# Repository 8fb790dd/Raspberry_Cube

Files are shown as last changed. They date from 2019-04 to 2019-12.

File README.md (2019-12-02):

# Raspberry_Cube
3D printable Case for Raspberry Pi 3B+ **Cluster** 

- stackable frame size 60x60x90 (without fan)
- consists of 4 printable parts (base-, mid- and top-plate, 30mm fan adapter)
- for two Raspberry PI's 3B+ with standard heatsinks on cpu, lan & memory
- for 60mm Fan or alternative 30mm Fan with additional adapter

### adapter
- [x] adapter for one 30mm fan for 1 Cube (2 Pi's)
- [ ] adapter for one 60mm fan for 2 stacked Cubes (4 Pi's)
- [ ] adapter for one 30mm fan for 2 stacked Cubes (4 Pi's)

### [ ] test effectiveness of design
  - [x] test one Cube with 30mm fan, running 2 Pi 3B+; see [test description](test1.md) and results.
  - [ ] test one Cube with 60mm fan, running 2 Pi 3B+
  - [ ] test two stacked Cubes with 60mm fan, running 4 Pi's 3B+

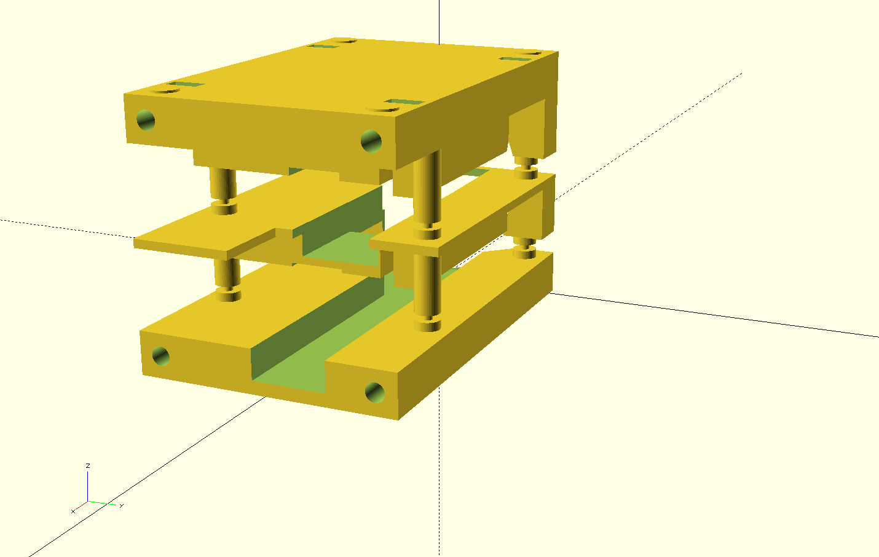
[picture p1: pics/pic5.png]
cube


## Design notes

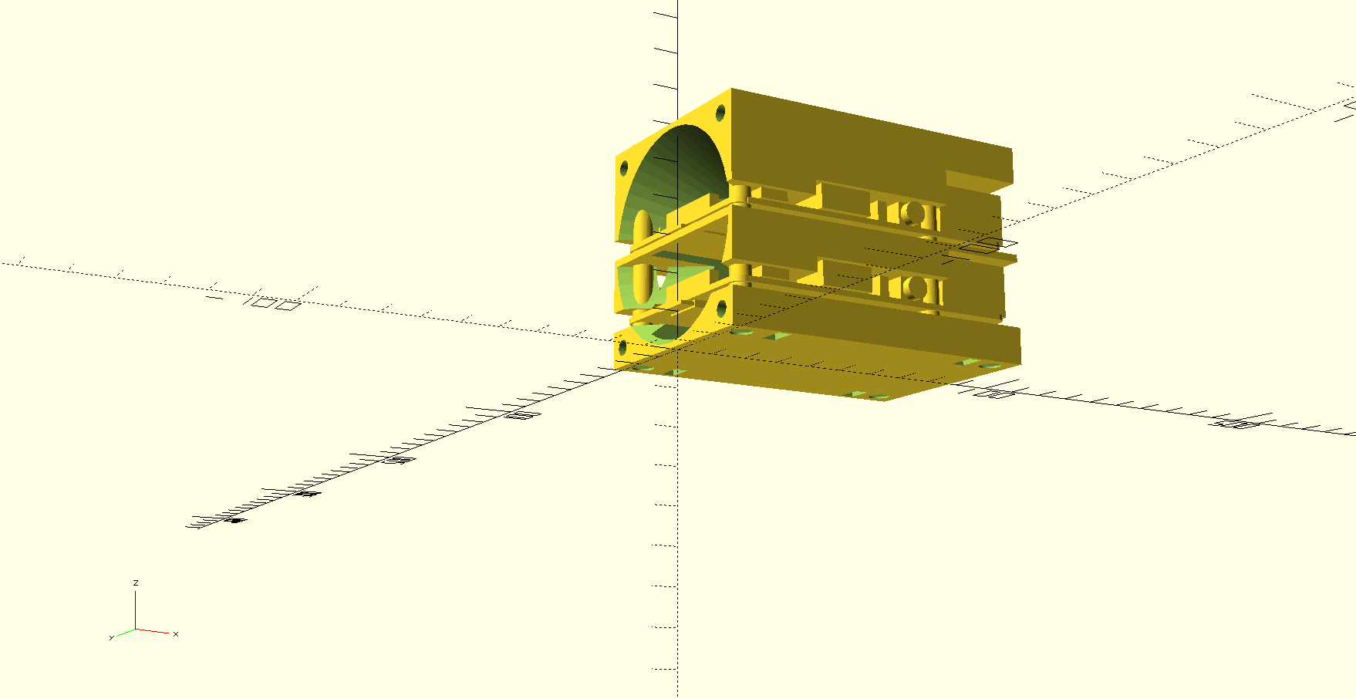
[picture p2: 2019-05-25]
pics/pic3.png

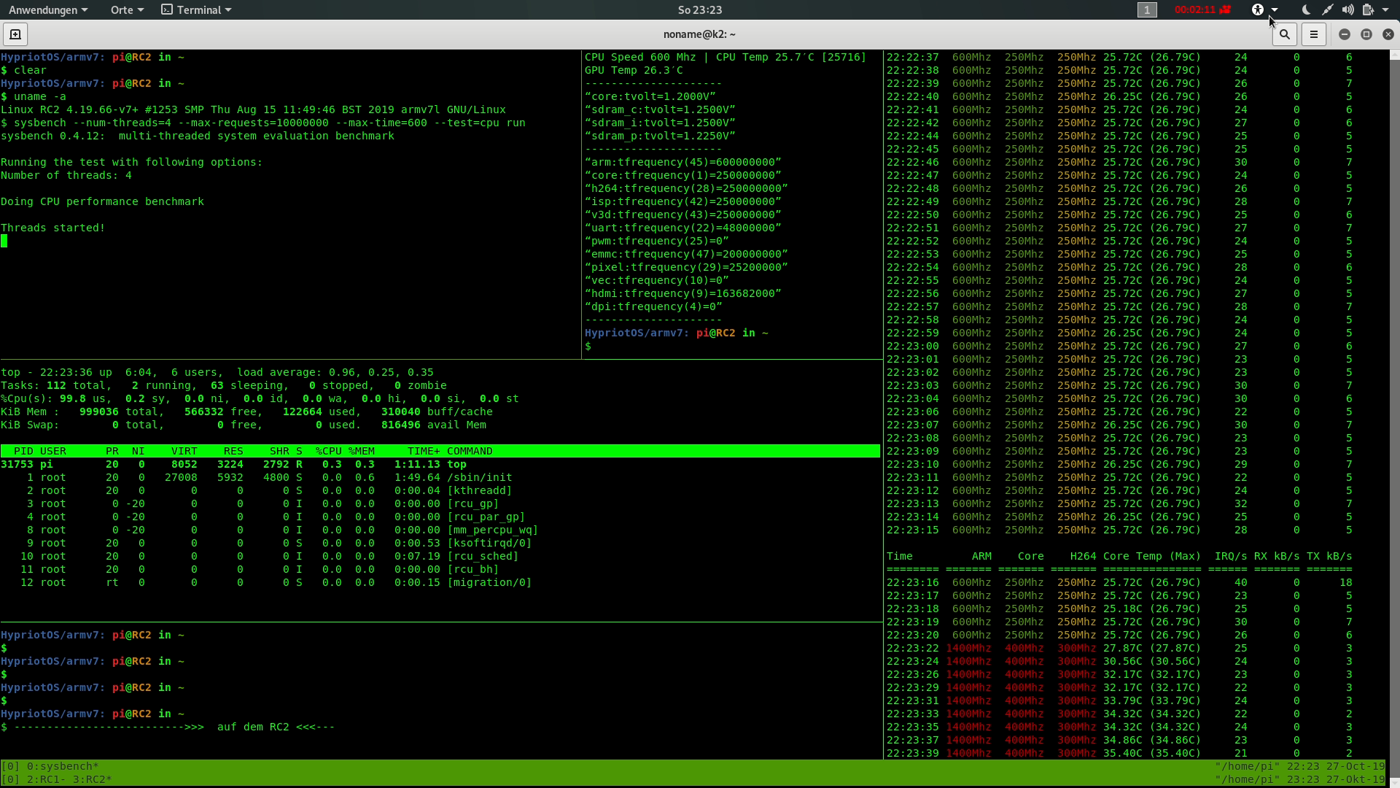
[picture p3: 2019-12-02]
pics/RC2_Start_Load_Screenshot from Screencast_27.10.2019_23:21:28.mp4.png

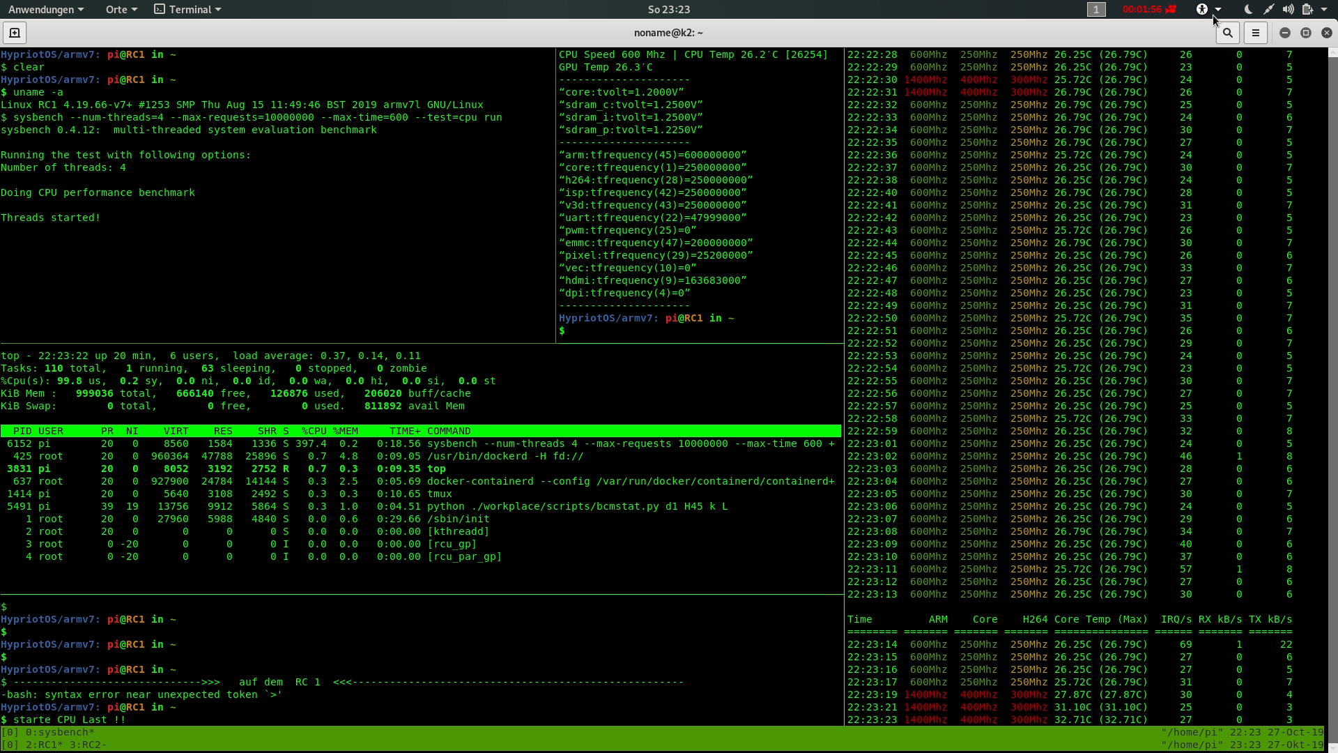
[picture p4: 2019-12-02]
pics/RC1_Start_Load_Screenshot from Screencast_27.10.2019_23:21:28.mp4.png

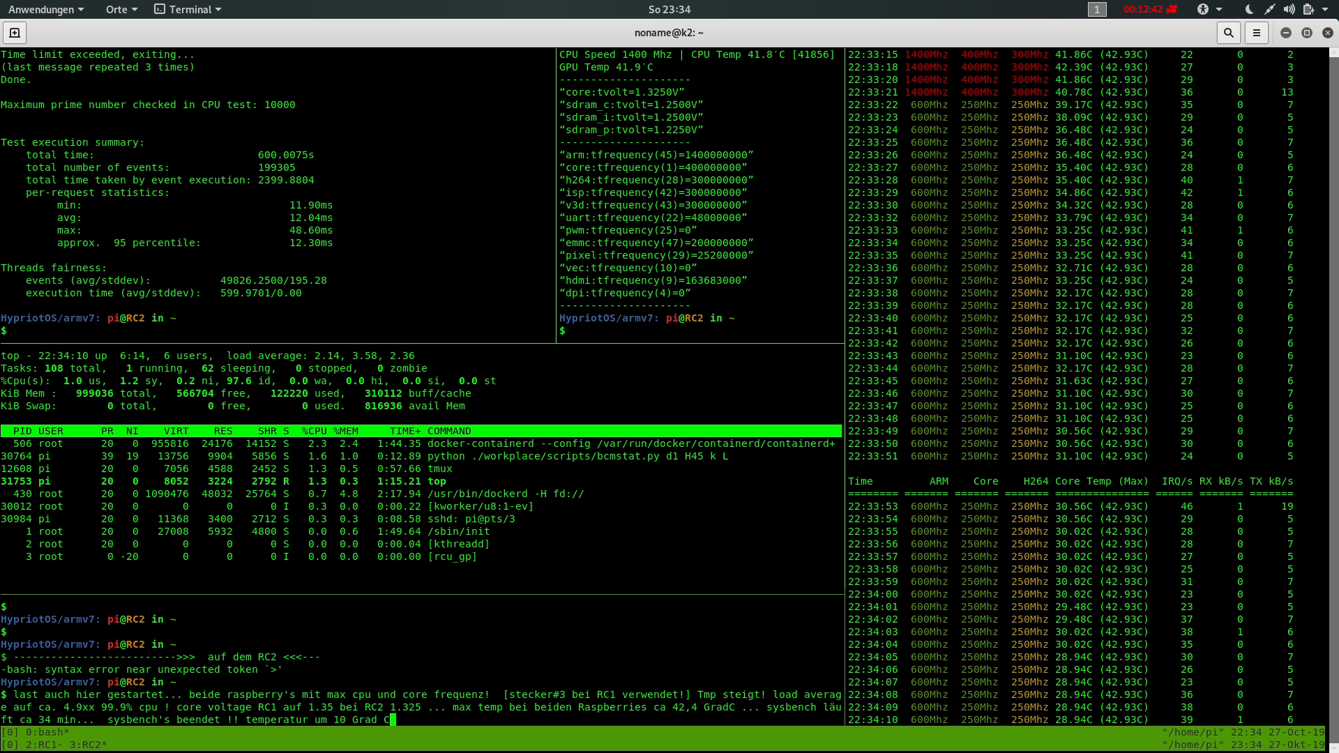
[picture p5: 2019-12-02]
pics/RC2_CoolDown_Screenshot from Screencast_27.10.2019_23:21:28.mp4.png

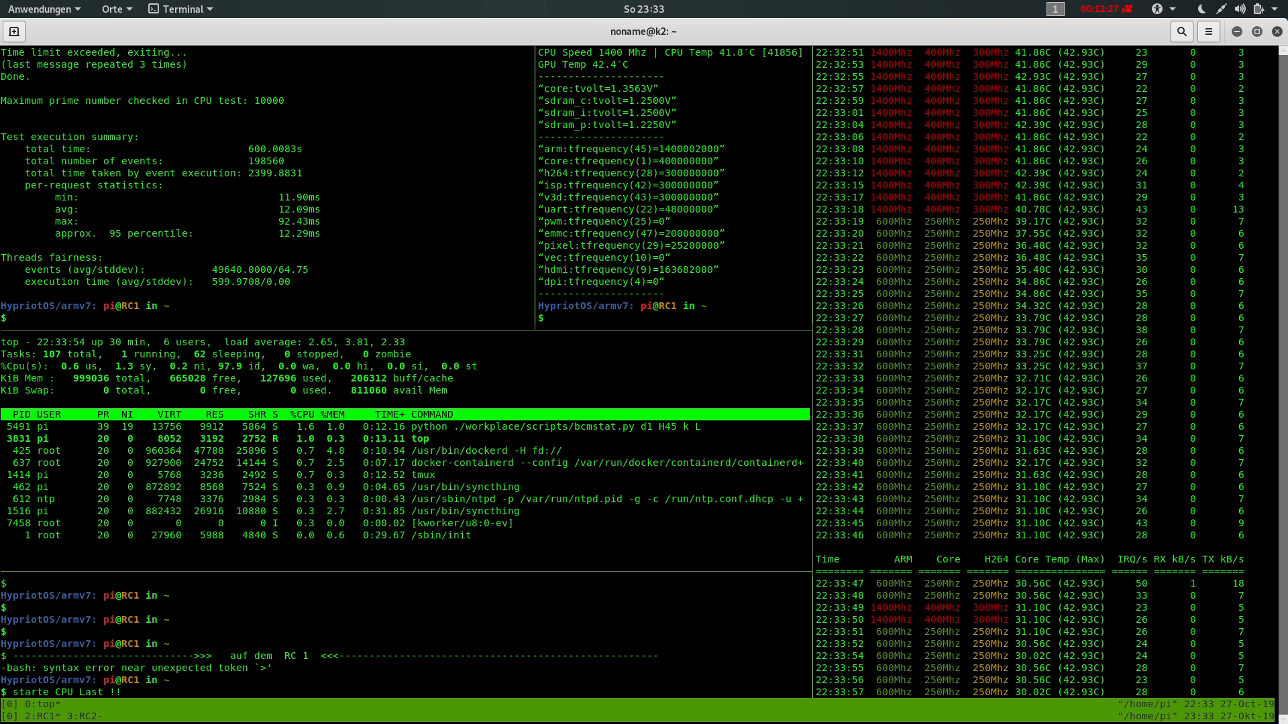
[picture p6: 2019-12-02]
pics/RC1_CoolDown_Screenshot from Screencast_27.10.2019_23:21:28.mp4.png

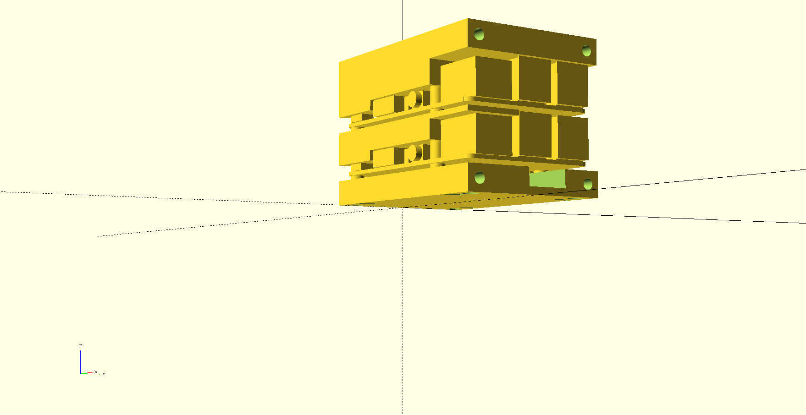
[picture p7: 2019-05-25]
pics/pic4.png

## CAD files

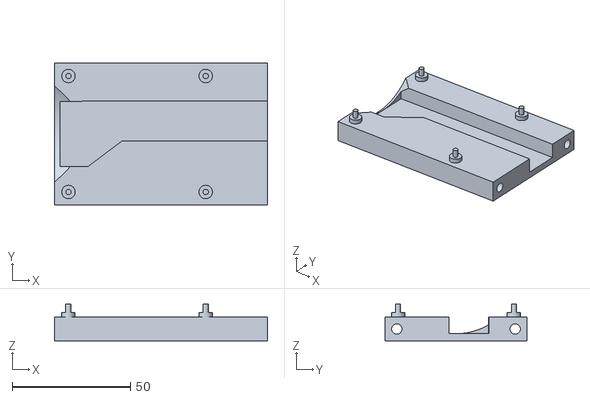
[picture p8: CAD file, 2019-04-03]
190401_Low_Frame.stl
90.0 x 60.0 x 15.5

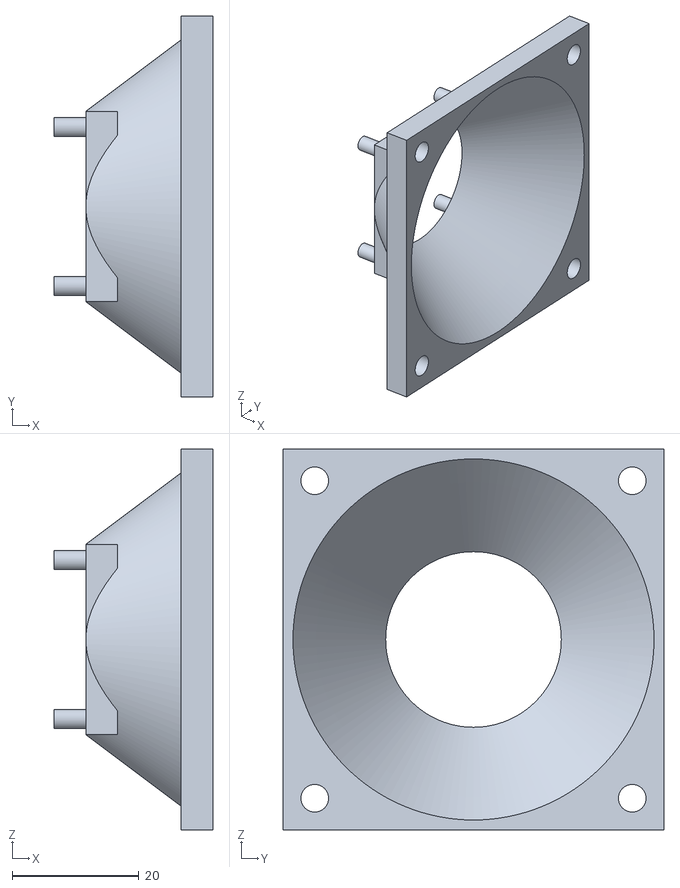
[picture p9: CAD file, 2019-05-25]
stl/190411_RB_Fan_Frame.stl
25.0 x 60.0 x 60.0

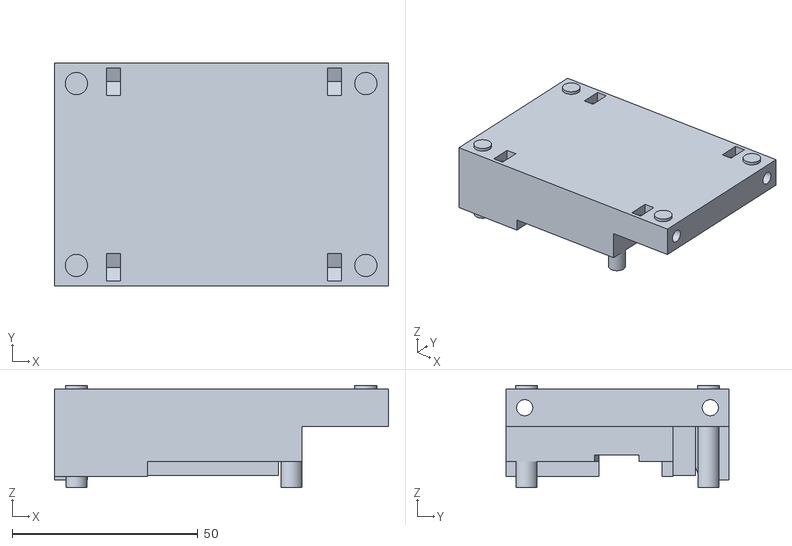
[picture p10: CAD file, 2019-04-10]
stl/190410_RB_Top_Frame.stl
90.0 x 60.0 x 27.5

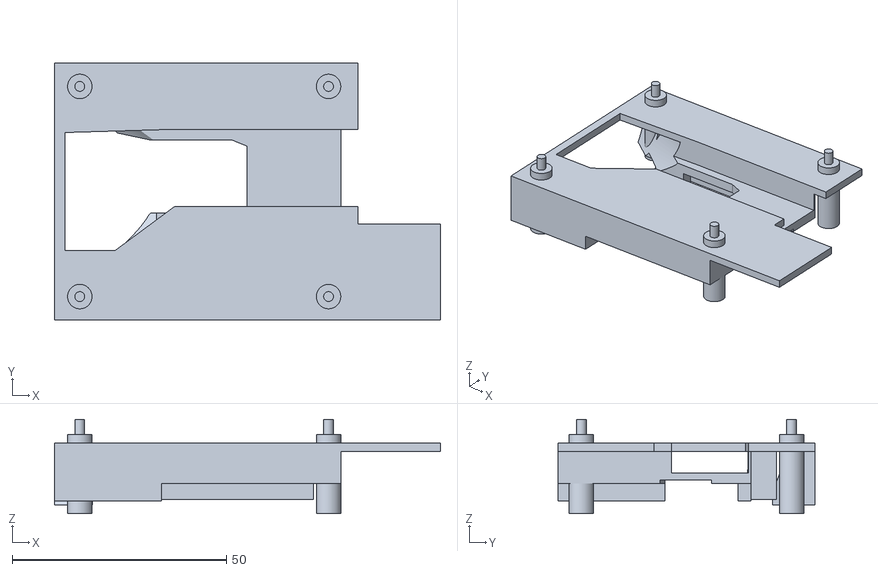
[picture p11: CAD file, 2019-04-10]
stl/190410_RB_Mid_Frame.stl
90.0 x 60.0 x 22.0

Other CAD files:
stl/190410_RB_Low_Frame.stl

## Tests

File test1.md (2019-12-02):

# test cooling of "Raspberry_Cube" case
## 27.10.2019 23:21
#### reference: f8ff9a73f449049f0244390ff263996b0694c69f  Screencast_27.10.2019_23:21:28.mp4
3D printable Case for Raspberry Pi 3B+ **Cluster** 

1. test **scenario**
  - 2 raspberry Pi 3B+ running in cube, headless named **RC1** & **RC2**
  - powered by 4 port 16 Watt USB power supply device (5.1V with max sum current 3.1A) 
  - 30mm fan running with 5V
  - environment temperature ca. 20 GradC
  - remote login to both Pi's via ssh and tmux
  - 2 nearly identical screens with panes for 
      online temp logging, voltages, top, start of load, ...

2. test procedureadded pics of 3d printed cases with 2 stacked Raspberries 3B+
  - start of sysbench on each pi's nearly simultan
  - run time of sysbench for 10 minutes (600 secs)
  - switching between screens to control voltage, temp and freq.

3. main results
  - after idle running for some minutes, the temperature started at ca. **26.8 Grad C** on each Pi
  - start full load with sysbench for 10 minutes
  - **max temperature** reached stayed below **43 Grad C** on each Pi
  - **no throttling** of cpu/gpu freq seen...

4. rough progress of RC2, (RC1 quiete similar)
  - 30 Grad C	4 sec
  - 32 Grad C	6 sec
  - 34 Grad C	13 sec
  - 36 Grad C	26 sec
  - 38 Grad C	38 sec
  - 40 Grad C	78 sec  1:18 min
  - 41 Grad C	146 sec	2:26 min
  - 42 Grad C	304 sec	4:24 min

## used screen logging
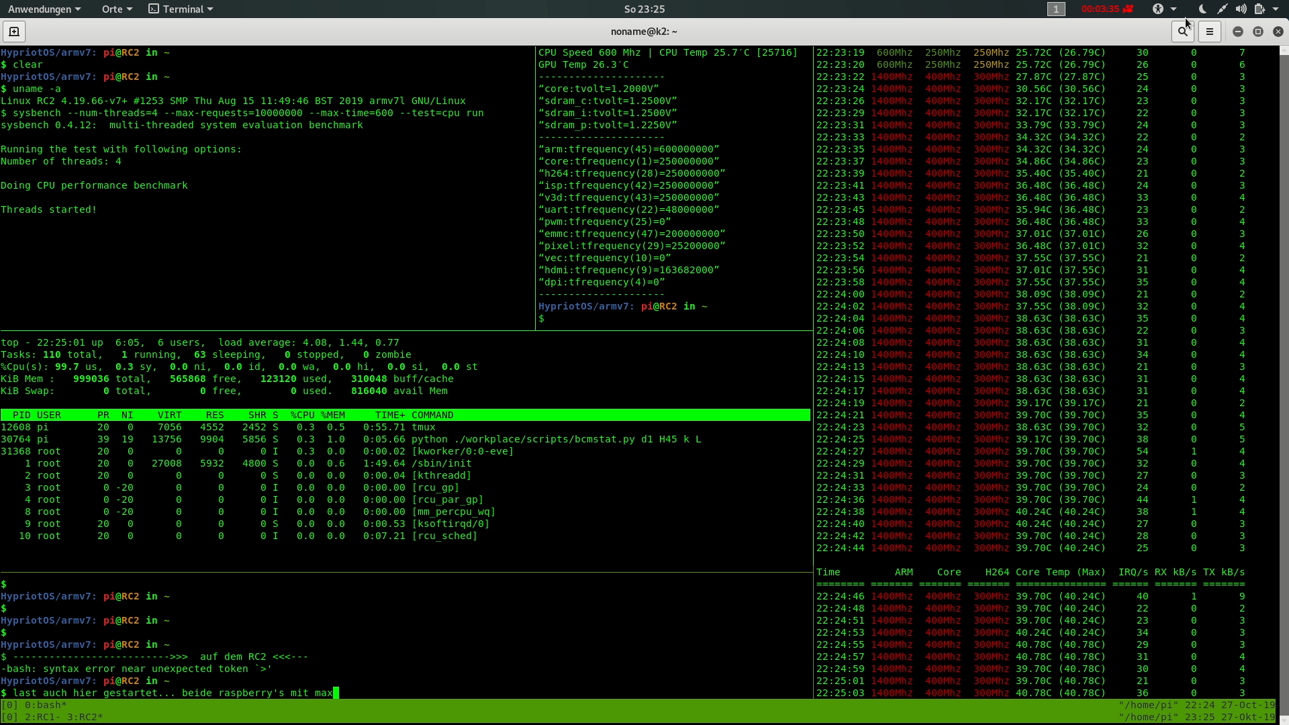
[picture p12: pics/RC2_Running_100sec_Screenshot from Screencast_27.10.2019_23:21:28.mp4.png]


## used "Cube" case
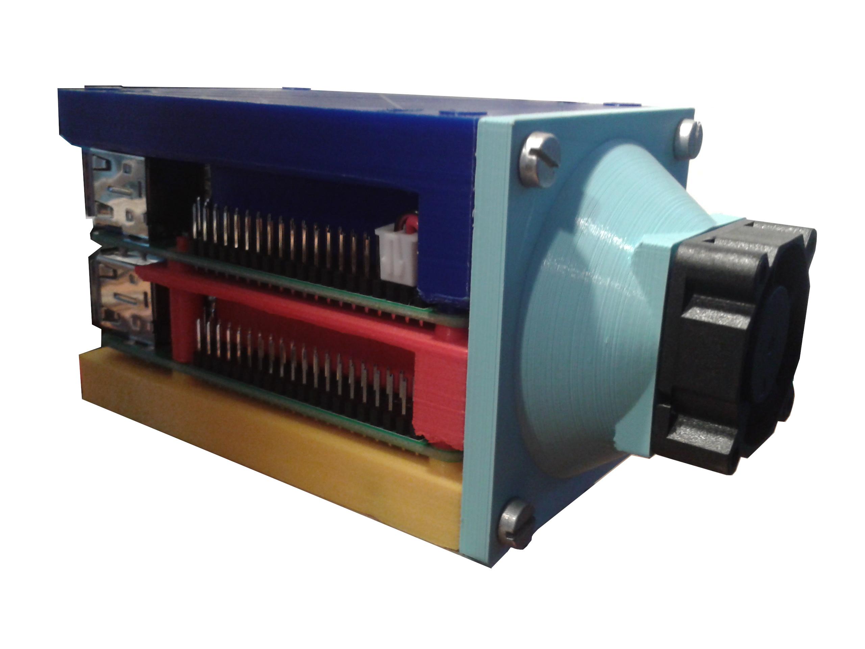
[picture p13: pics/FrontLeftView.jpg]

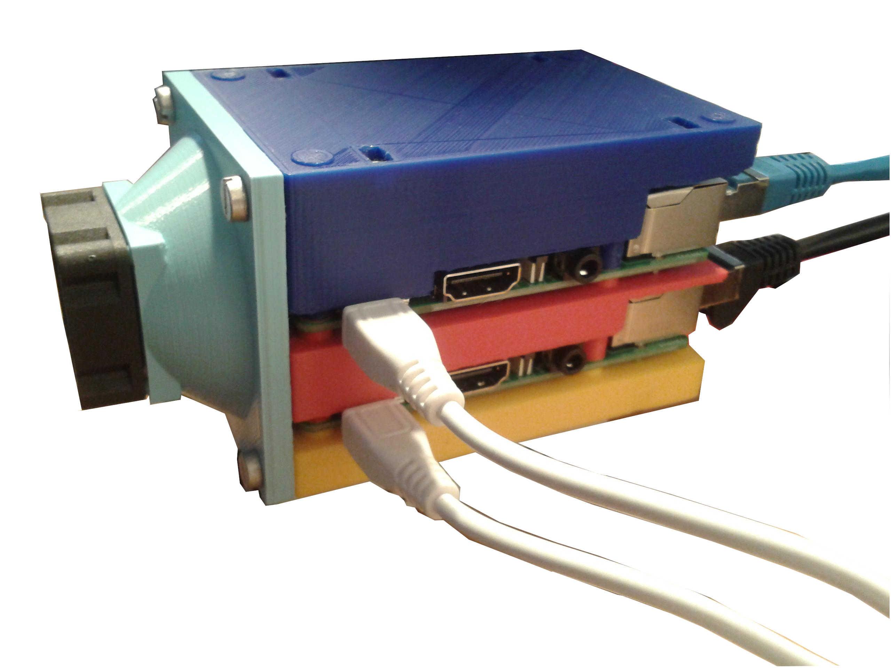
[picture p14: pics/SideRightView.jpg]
cube_sr

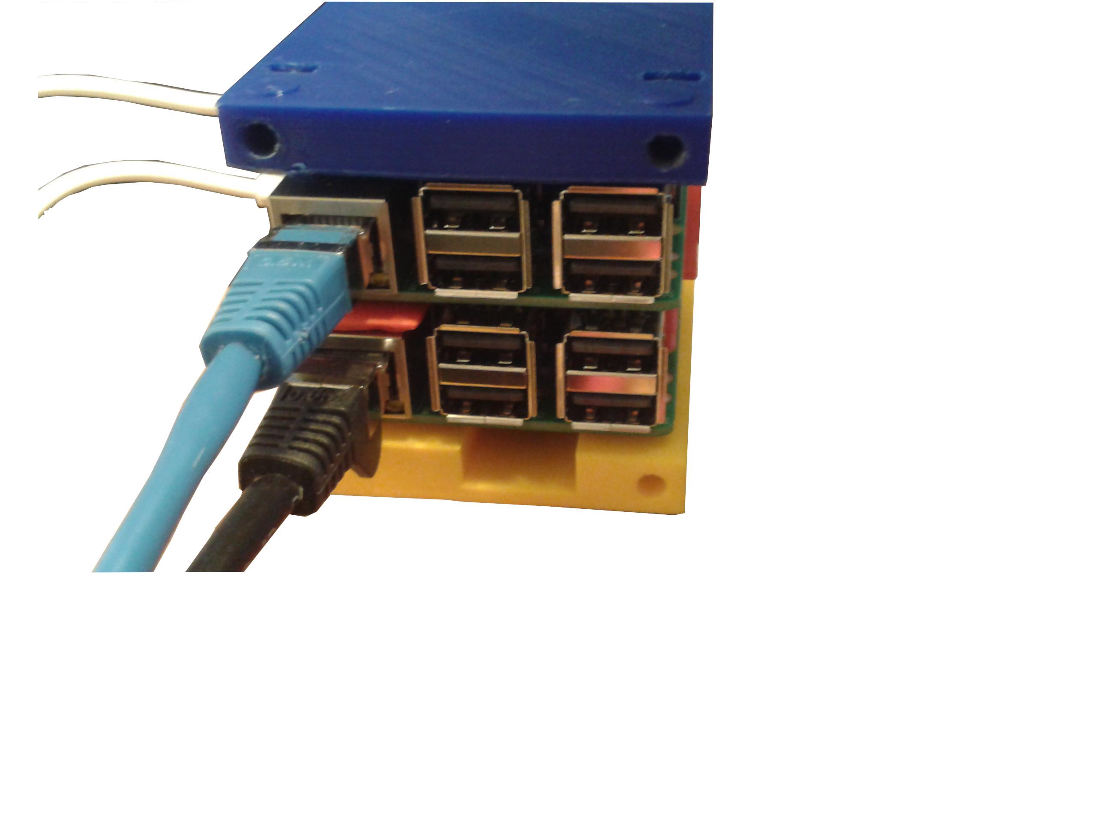
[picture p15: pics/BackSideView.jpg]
cube_bs


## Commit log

2019-04-10 error correction stacking connectors and distance poles
    [190401_Mid_Frame.stl, 190401_Top_Frame.stl, 190410_RB_Low_Frame.stl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]
2019-04-28 added pic and moved stl
    [190410_RB_Low_Frame.stl, 190410_RB_Mid_Frame.stl, 190410_RB_Top_Frame.stl]
2019-05-25 added stl for additional 30mm fan adapter
    [190411_RB_Fan_Frame.stl]
2019-12-01 added pics of 3d printed cases with 2 stacked Raspberries 3B+ tested cooling behaviour under full load with sysbench on both boards
2019-12-01 tested cooling behaviour under full load with sysbench on both boards
    tested cooling behaviour under full load with sysbench on both boards
    added pics of 3d printed cases with 2 stacked Raspberries 3B+
2019-12-02 status update
    added reference to first test with 30mm fan
